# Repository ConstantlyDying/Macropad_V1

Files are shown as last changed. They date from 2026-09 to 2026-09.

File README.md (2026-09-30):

<p align="center">
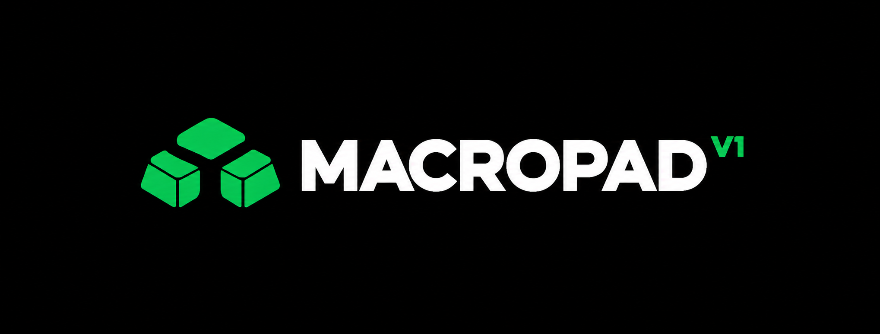
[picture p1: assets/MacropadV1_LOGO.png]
Macropad V1
  
</p>

<h1 align="center">MACROPAD V1</h1>

<p align="center">
  <strong>
    A wireless Raspberry Pi Pico W macropad with RGB lighting,
    rotary encoders, an OLED display and haptic feedback!
  </strong>
</p>

<div align="center">





</div>

<p align="center">
  <a href="#key-features">Key Features</a> •
  <a href="#pcb">PCB</a> •
  <a href="#case">Case</a> •
  <a href="#credits">Credits</a> •
  <a href="#license">License</a>
</p>

<p align="center">

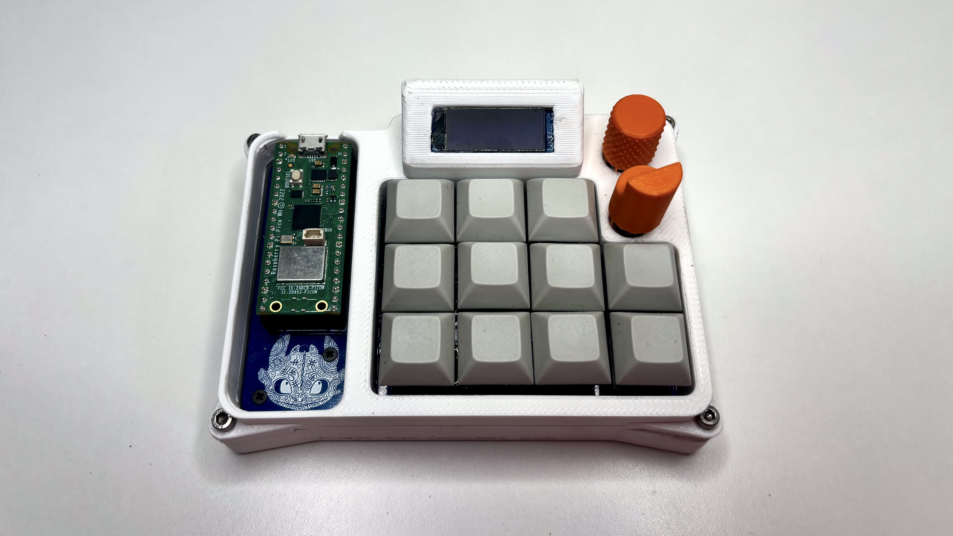
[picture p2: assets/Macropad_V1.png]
Macropad V1
  

</p>

I've made this as in my experience off the shelf macropads are way too expensive for the features they offer and are also very generic.
This is an alternative that is actually unique with multiple customizable switches, rotary encoders, a display, Wireless & Wired connectivity and insanely good haptics.

## Key Features

- **11 programmable keys** for custom shortcuts, macros, and commands
- **2 dedicated profile keys** for switching between profiles
- **Dual rotary encoders** for profile selection, volume, endless scrolling, and custom controls
- **OLED display** for showing the active profile and other information
- **Haptic feedback** for responsive physical feedback
- **QMK firmware** for controlling everything through the Pico
- **Vial configuration** for remapping keys and controls without reflashing firmware

## PCB 

Designed in KiCad!

### Schematic

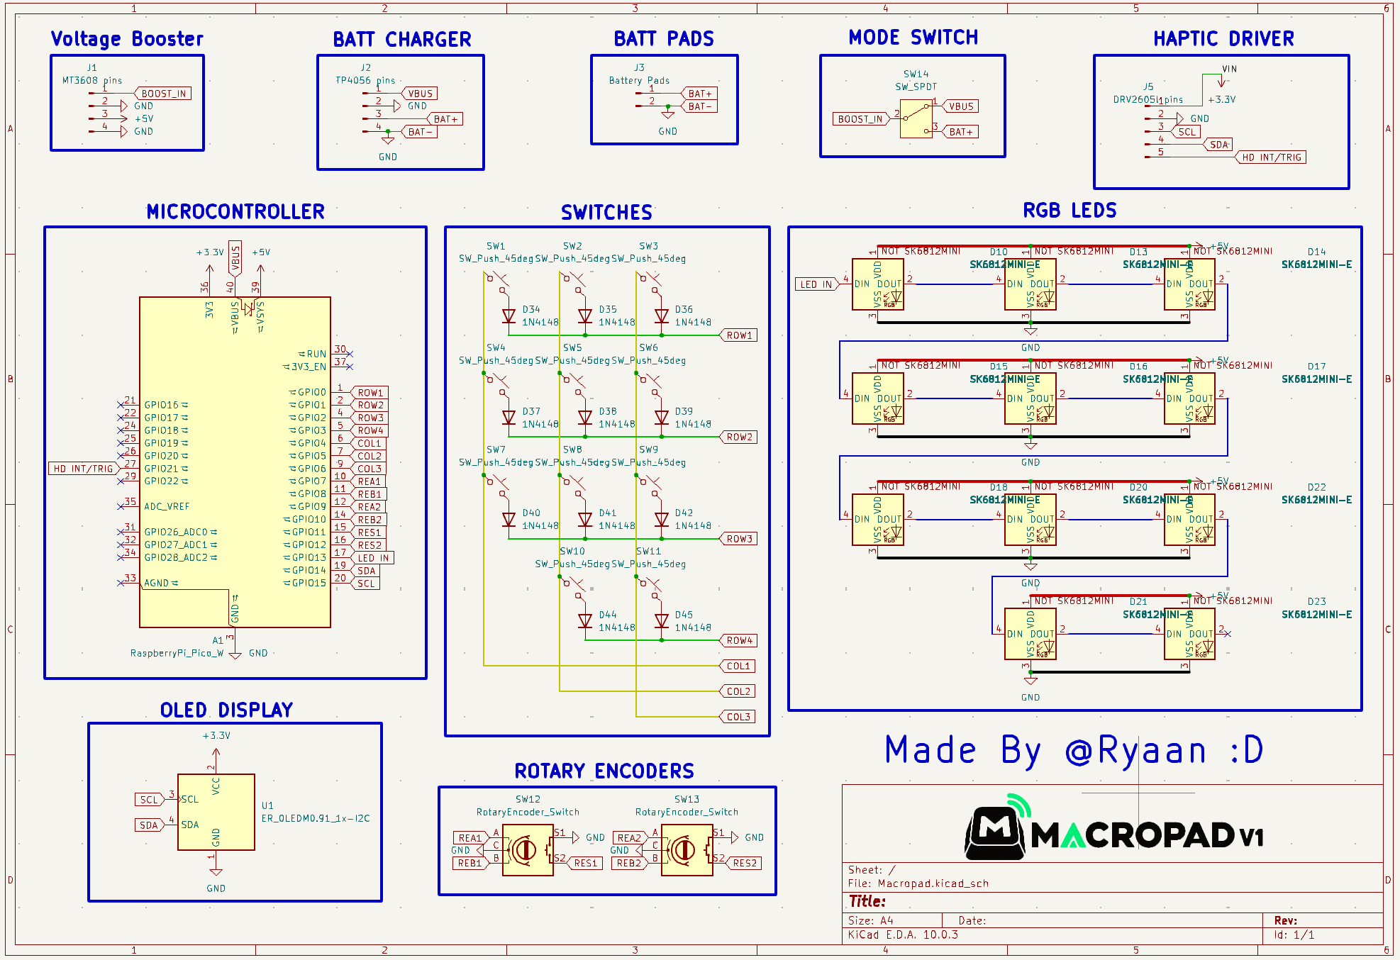
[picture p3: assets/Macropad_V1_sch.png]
Macropad V1 schematic
  

</p>

### PCB Layout:

**Front:**

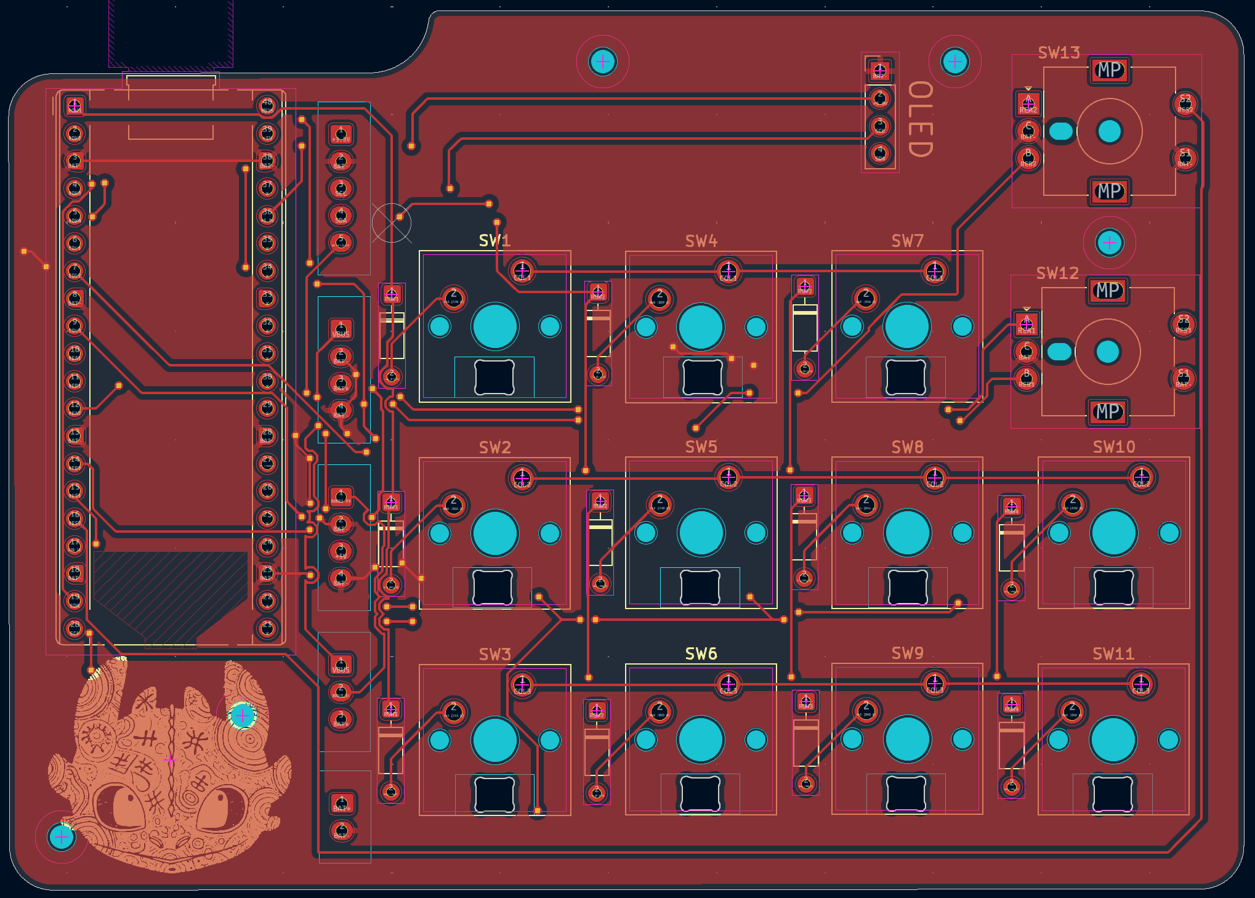
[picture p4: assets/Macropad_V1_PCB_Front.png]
Macropad V1 schematic
  

</p>

**Back:** 

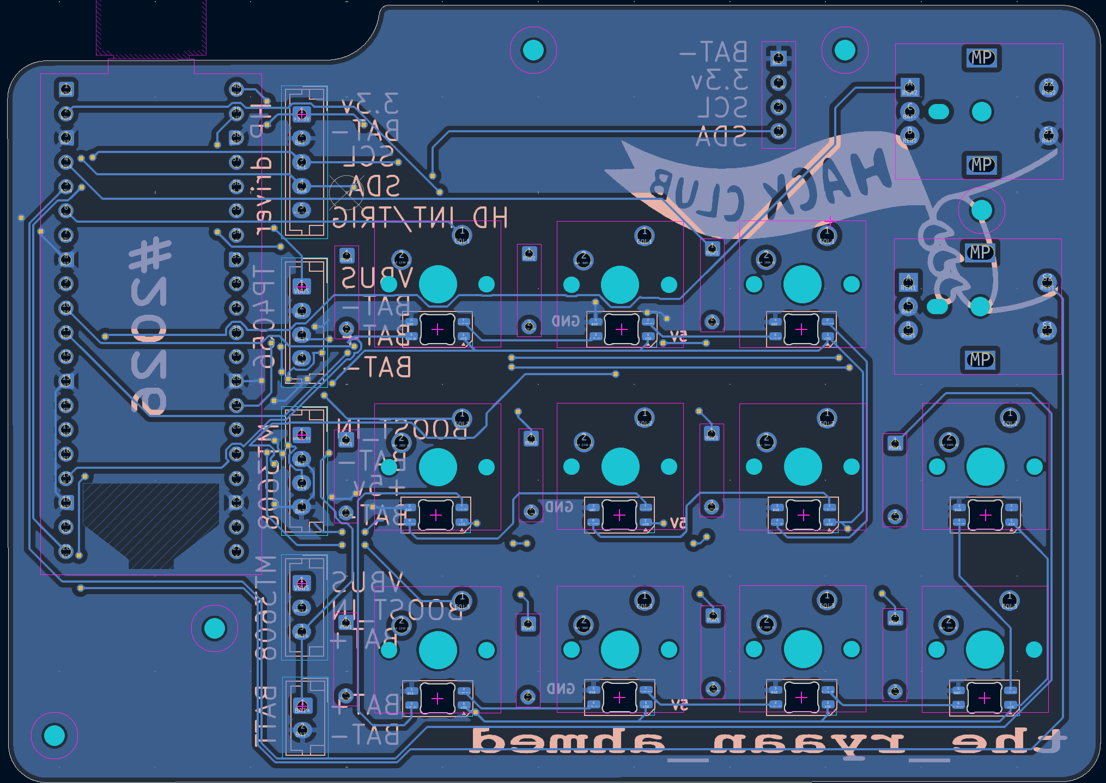
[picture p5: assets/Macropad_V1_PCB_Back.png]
Macropad V1 schematic
  

</p>

### Copper Layers:

**F_Cu:**

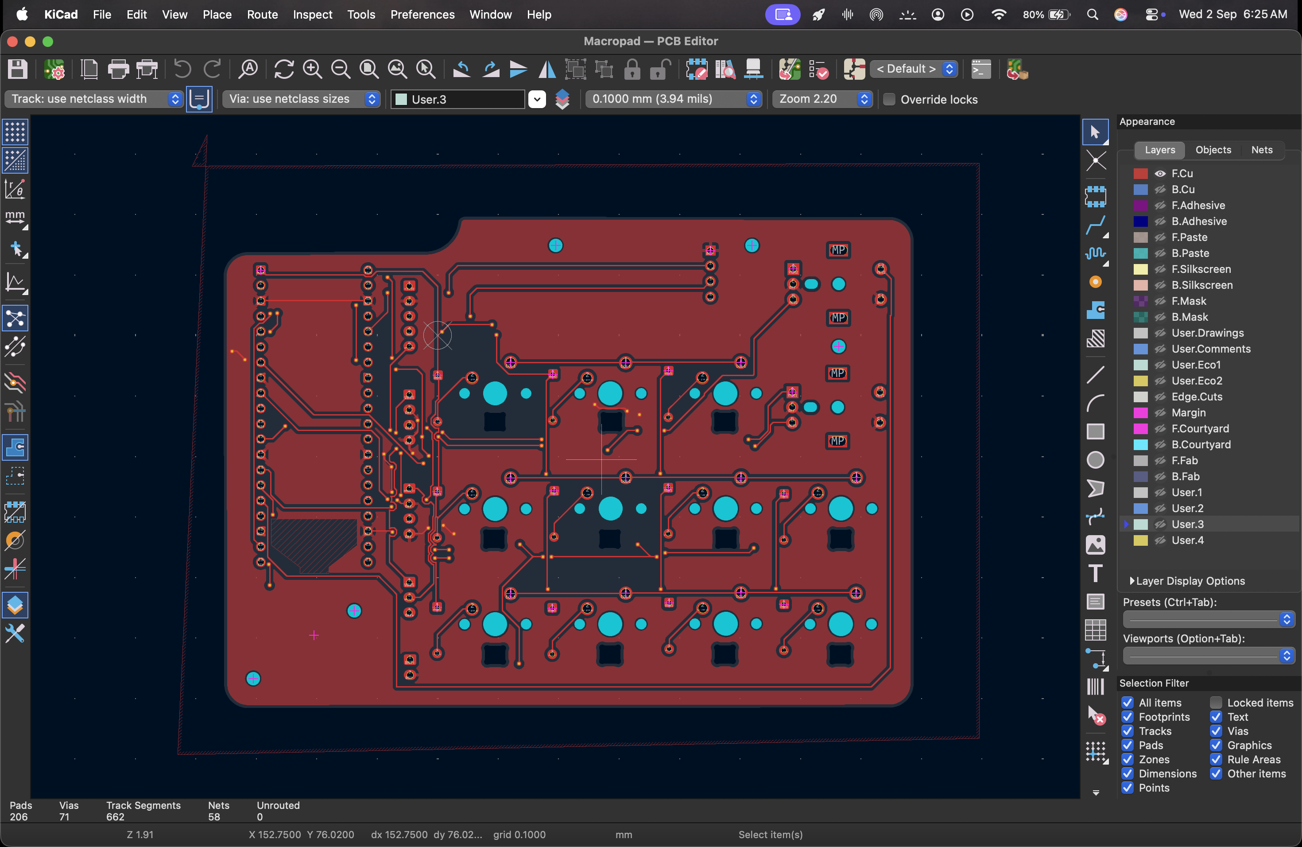
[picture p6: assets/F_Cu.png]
  

</p>

**B_Cu:**

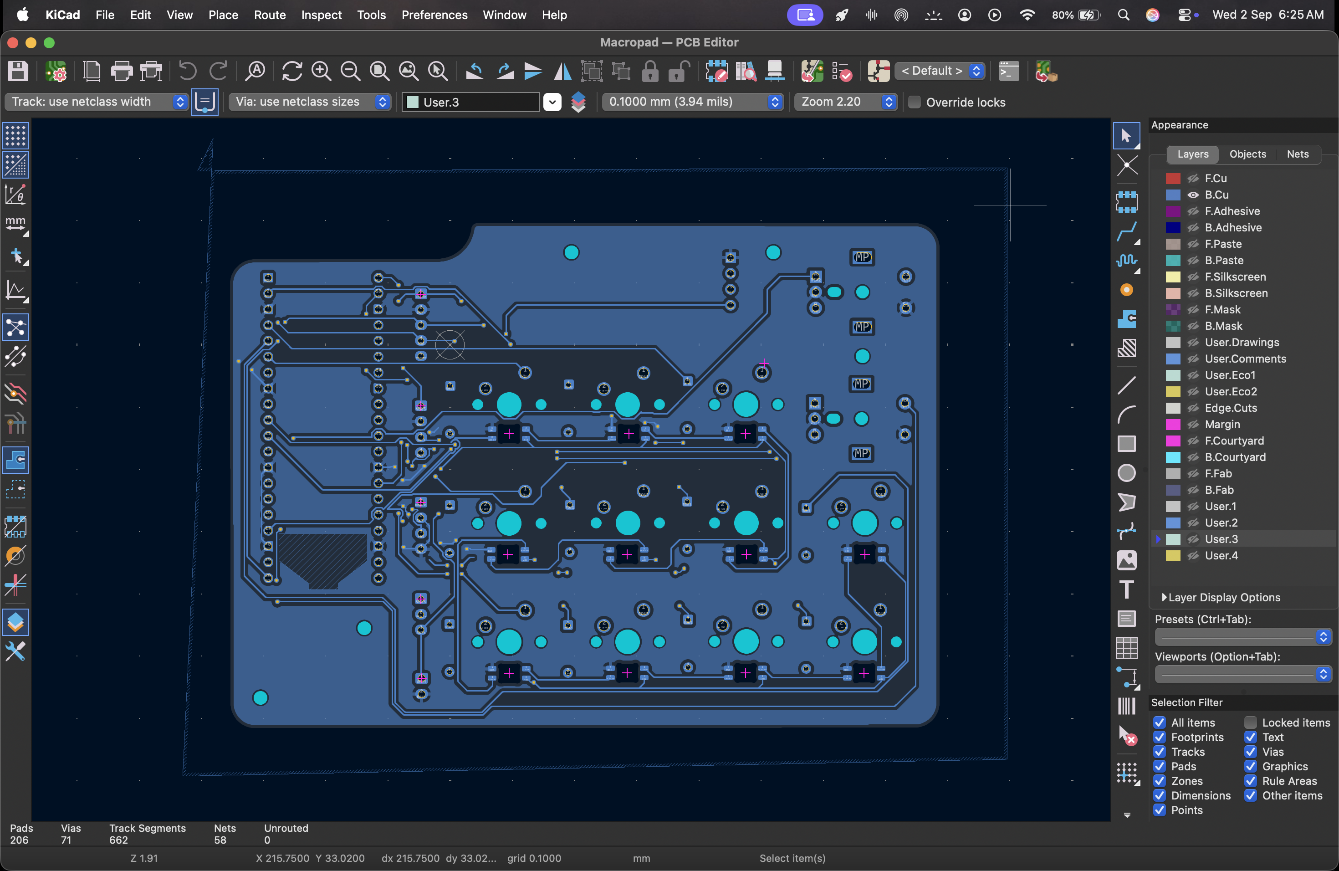
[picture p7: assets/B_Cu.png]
  

</p>

Board dimensions: 115mm x 80mm

## Case

Custom designed case in Fusion 360 with practical features:

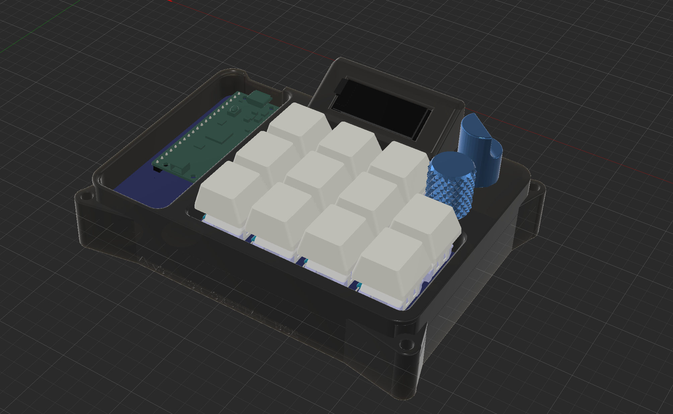
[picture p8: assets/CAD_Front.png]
Case Front View

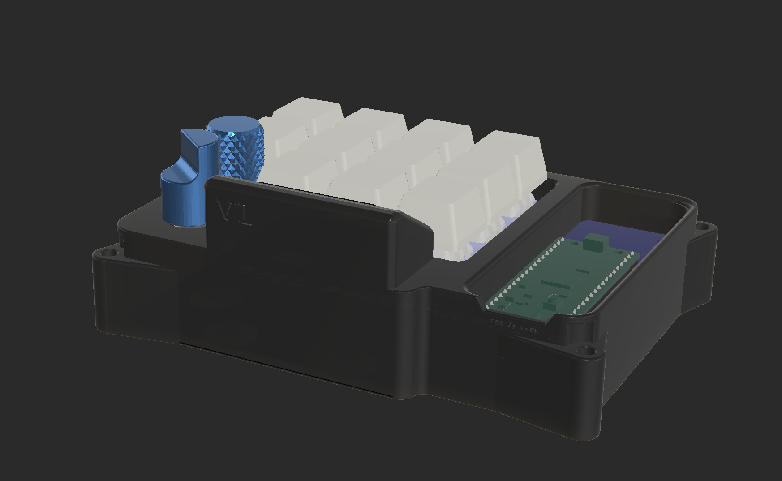
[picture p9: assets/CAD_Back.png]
Case Back View


Features:
- **USB port cutout** with flush cable routing
- **Raised-Angled Display** for easier status and profile viewing
- **Heatset inserts** for secure assembly with slotted cylindrical head screws
- **Rounded corners** for aesthetics and safety

## 3D Renders

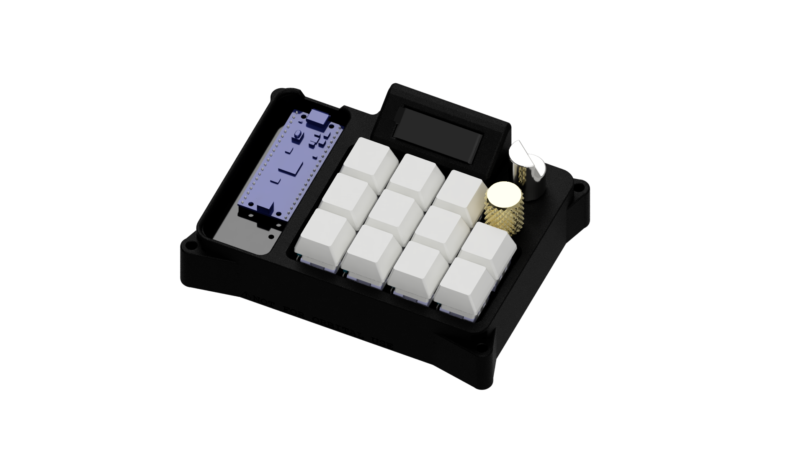
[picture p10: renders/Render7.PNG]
Render 1

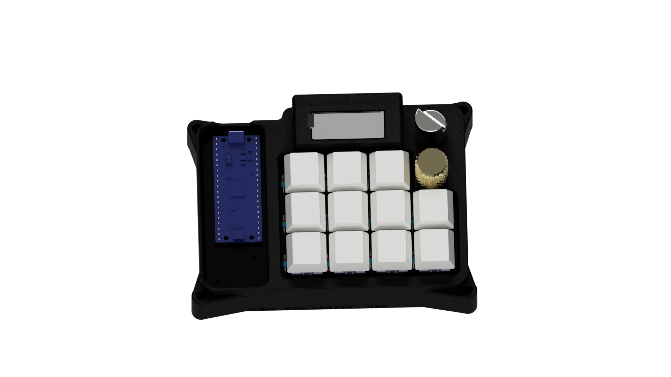
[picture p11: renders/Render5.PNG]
Render 1

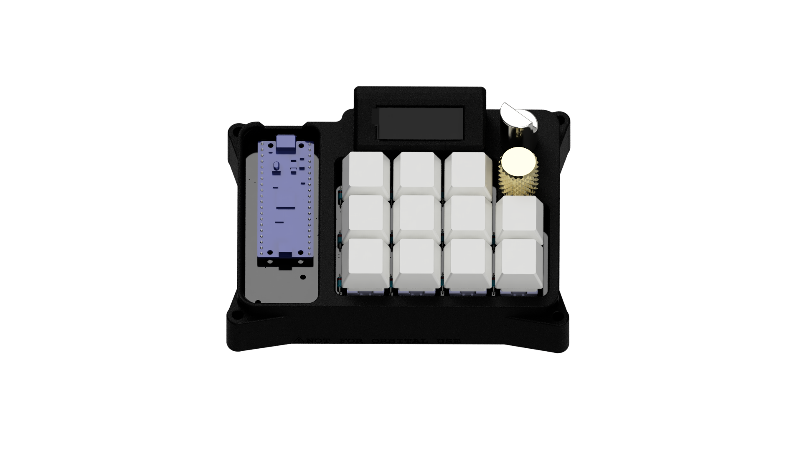
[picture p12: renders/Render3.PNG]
Render 1

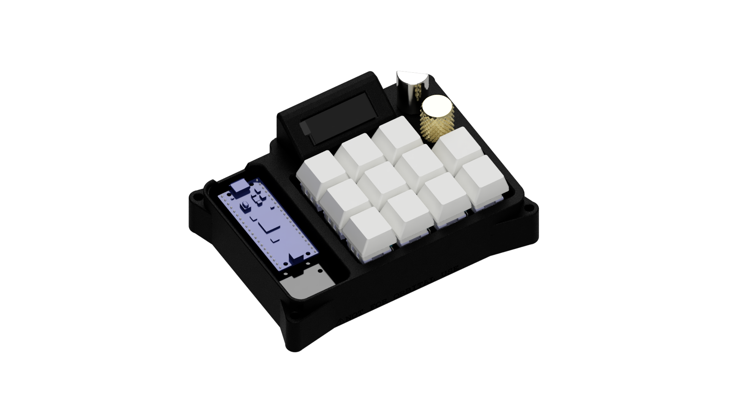
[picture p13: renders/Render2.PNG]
Render 1

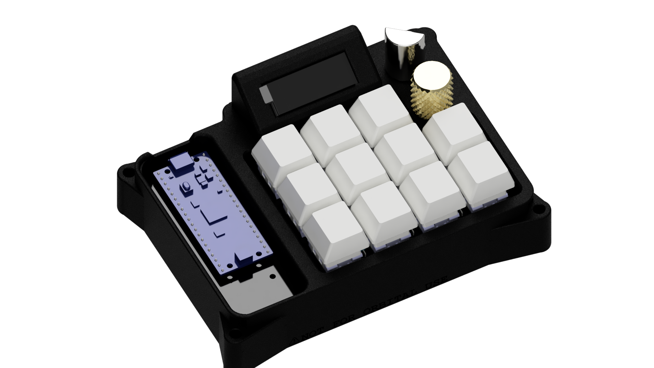
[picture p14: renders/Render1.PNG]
Render 1


## Credits

This project uses:

- [KiCad](https://www.kicad.org/)
- [Autodesk Fusion](https://www.autodesk.com/) for case design and renders
- [RaspberryPi](https://www.raspberrypi.com)
- [QMK](https://qmk.fm/) for the firmware

## You may also like...

- [Force-Feedback-Racing-Sim](https://github.com/ConstantlyDying/Force-Feedback-Racing-Sim) – A Budget friendly - DIY Racing simulator, powered by an Arduino Leonardo and a beefy 500w motor!!

### AI USAGE DECLARATION:
Used AI for a little assistance with firmware as it is my first time programming in these languages

## License

MIT

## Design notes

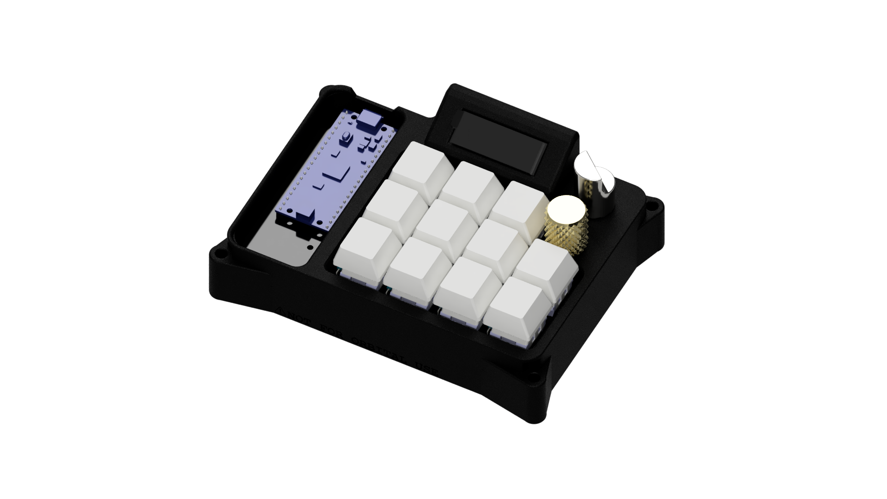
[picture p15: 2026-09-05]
renders/Render6.PNG

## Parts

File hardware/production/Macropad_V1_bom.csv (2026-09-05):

Designator | Footprint | Quantity | Value | LCSC Part #
A1 | RaspberryPi_Pico_Common_THT | 1 | RaspberryPi_Pico_W
D10, D13, D14, D15, D16, D17, D18, D20, D21, D22, D23 | LED_SK6812MINI-E_3.2x2.8mm_P1.5mm_ReverseMount | 11 | SK6812MINI-E
D34, D35, D36, D37, D38, D39, D40, D41, D42, D44, D45 | D_DO-35_SOD27_P7.62mm_Horizontal | 11 | 1N4148
J1 | JST_EH_B4B-EH-A_1x04_P2.50mm_Vertical | 1 | MT3608 pins
J2 | JST_EH_B4B-EH-A_1x04_P2.50mm_Vertical | 1 | TP4056 pins
J3 | JST_EH_B2B-EH-A_1x02_P2.50mm_Vertical | 1 | Battery Pads
J5 | JST_EH_B5B-EH-A_1x05_P2.50mm_Vertical | 1 | DRV2605l pins
SW1, SW10, SW11, SW2, SW3, SW4, SW5, SW6, SW7, SW8, SW9 | SW_Cherry_MX_1.00u_PCB | 11 | SW_Push_45deg
SW12, SW13 | RotaryEncoder_Alps_EC11E-Switch_Vertical_H20mm_MountingHoles | 2 | RotaryEncoder_Switch
SW14 | JST_EH_B3B-EH-A_1x03_P2.50mm_Vertical | 1 | SW_SPDT
U1 | PinHeader_1x04_P2.54mm_Vertical | 1 | ER_OLEDM0.91_1x-I2C

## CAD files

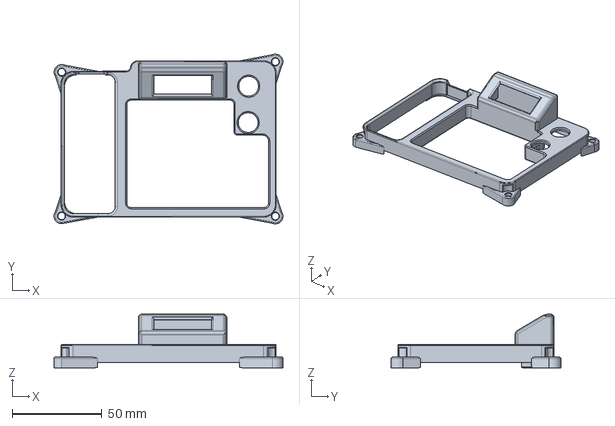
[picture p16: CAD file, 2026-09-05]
hardware/case/case top main.step
127.8 x 94.7 x 30.0 mm

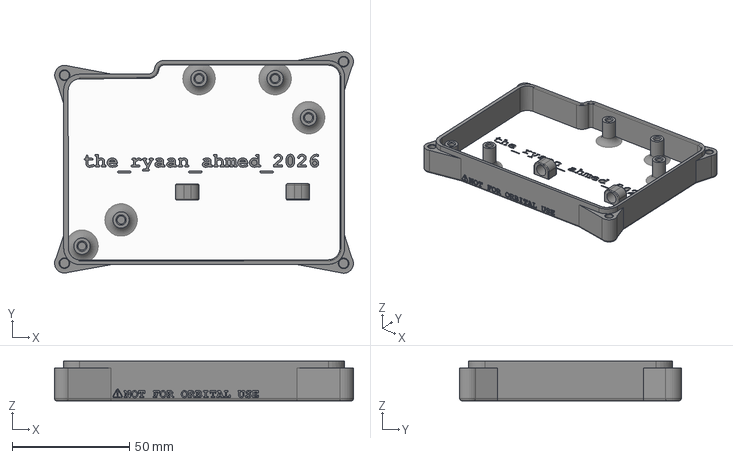
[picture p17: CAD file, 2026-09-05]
hardware/case/case bottom main.step
127.7 x 94.7 x 17.0 mm

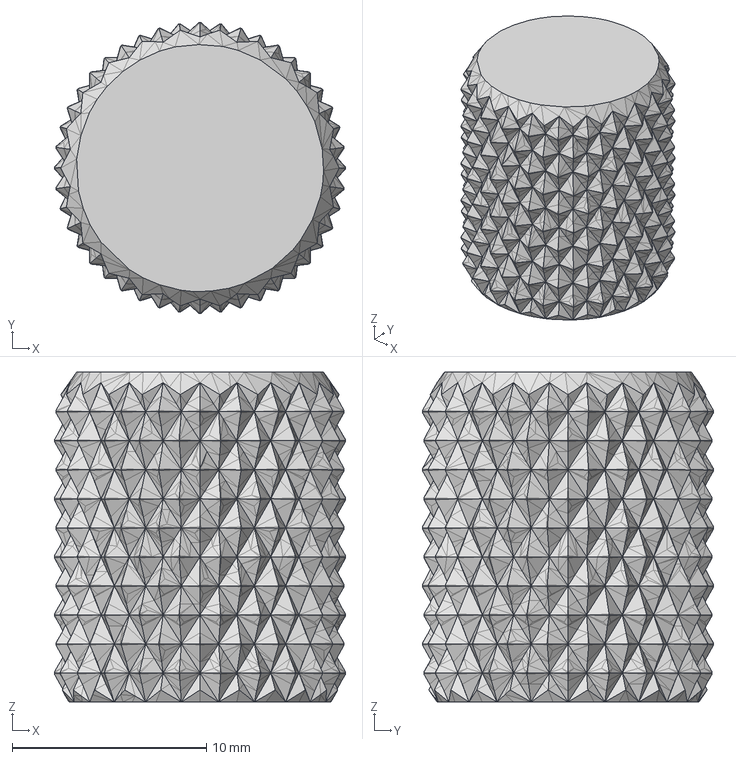
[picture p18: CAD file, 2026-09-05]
hardware/case/KNOB 2.step
15.0 x 15.0 x 17.0 mm

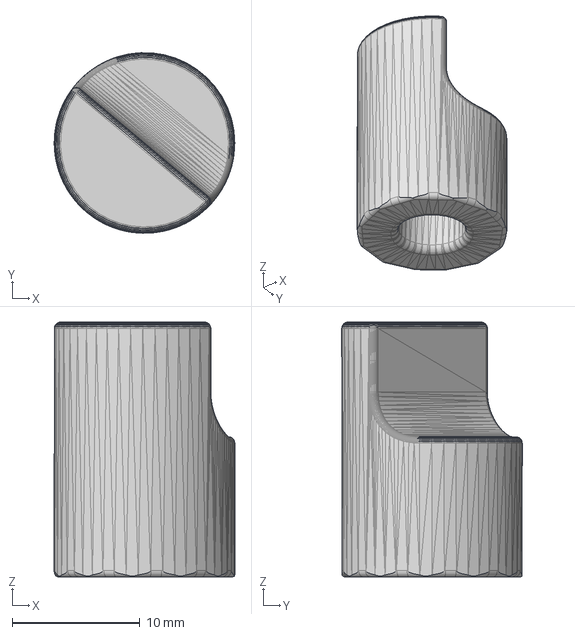
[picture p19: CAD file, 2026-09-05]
hardware/case/KNOB 1.step
14.2 x 14.2 x 20.0 mm

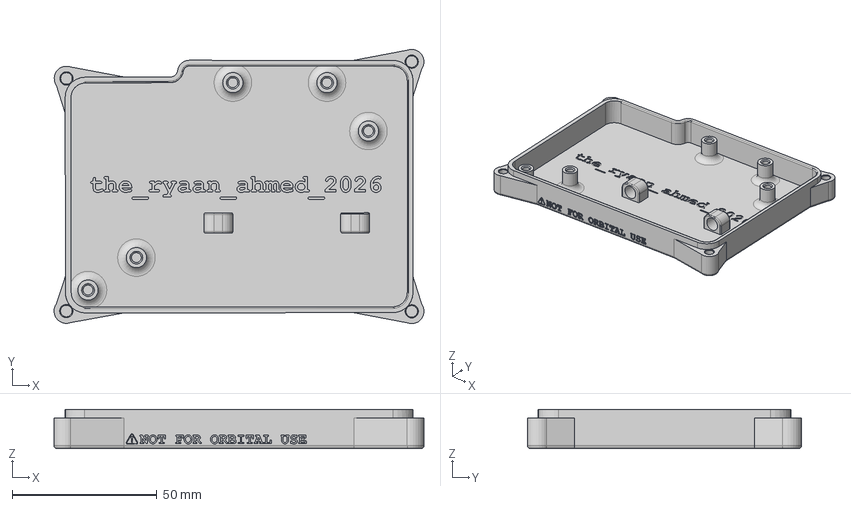
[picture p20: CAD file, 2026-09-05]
hardware/case/Macropad V1_CASE BOTTOM SLIM.step
127.7 x 94.7 x 13.5 mm

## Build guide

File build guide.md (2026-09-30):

# Build Guide:

### Step 1:
Get all the parts (Case top; case bottom; Soldered PCB; screws; Display: heated inserts).

### Step 2:
Insert the heated inserts into their places.

### Step 3:
Place the daughter boards and insert haptic actuator into its slot.
Place PCB on top of case bottom and screw it in place.

### Step 3:
Place case top on top of the PCB and case bottom and screw it in place.

### Step 4:
Connect the display with its connector and place it in its slot on case top.

### Step 5:
Plug the Pico in and flash the firmware.

### Step 6:
Attach all the keycaps and encoder caps.

### Step 7:
Done!!

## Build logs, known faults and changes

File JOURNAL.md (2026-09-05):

title: "Macropad"
author: "Ryaan"
description: "A wireless macropad with insane haptics!!, comes with 11 switches and 2 rotary encoders."
created_at: "2024-05-07"

# May 8th: Began working on my macropad idea

Today, i decided to start working on a macropad, as i submitted my other project and am impatient:)
I have no clue on how to build one, just heard its very popular. I mainly went around looking for inspiration, and how to start with the fundamentals like the schematics.
I imported a few libraries of symbols and foot prints to kicad. Now i have to figure out how to make a switch matrix, as im planning on using 11 switches along with 2 rotart encoders and a display, and the SEEED xiao MC barely has pins!! so yea.

https://public.lapse-hackclub.link/timelapses/Jx6Lpbg7D-ae/timelapse-Jx6Lpbg7D-ae.mp4







**Total time spent: 1h**

# May 9th: Continued working on schematics

I continued making the schematics. I went thru a few hackpads others made for inspirations, and to see if i can understand better by goin thru those schematics. I made the switch matrix, and added the rotary encoder sign. I also did a bit of research and am gonna go with the 0.91inch oled display. I also added diodes to the switches. Well im not sure how this goes, its my first time making a macropad:)

https://public.lapse-hackclub.link/timelapses/vdwkVHPgRyA7/timelapse-vdwkVHPgRyA7.mp4



**Total time spent: 1h 18m**

# May 10th: Continued working on schematics

i continued working on the schematics. I added and wired the switch matrix, rotary encoders, the oled display and the rgb led's. I just realised i wanna make the macropad wireless too, so im gonna add a raspbery pico W later.

https://public.lapse-hackclub.link/timelapses/AWpfal8JZQ22/timelapse-AWpfal8JZQ22.mp4





**Total time spent: 1h 32m**

# May 10th: Continued working on schematics

i continued working on my schematics:)
I finished re arranging all the components, and then wired them up, (colour coded obv). Then a random idea js struck my mind: why not make it wireless!
so i went ahead with a raspberry pi pico W, and started researching on how to make it wireless and functional.
I decided on like a 1000mah 3.7v battery(might change later tho..), and a TP4056 module for charging:)

https://public.lapse-hackclub.link/timelapses/nB5B7usA8Ic8/timelapse-nB5B7usA8Ic8.mp4





**Total time spent: 1h 3m**

# May 10th: Continued working on schematics

I am still continuing on my schematics lmaoo:)
As i thought of using whatever module im adding to my pcb as daughter modules, i had to find their symbols, which ofc were not there, so i just decided to use connectors instead. I then changed the name and labelled the pins on these connectors to math the TP4056. Then i added 2 connectors similarly for the battery pads and labelled them. I repeated the same for the MT3608 buck boost converter too. Then i added a spdt slide switch and wired them all up!. The main idea was that; there woul be two modes which the switch can toggle: one was the wired one, where the macropad gets connected via usb and doesn't use battery power, and the 2nd is wireless, where the macropad connects via bluetooth, utilizing the power of the battery.

https://public.lapse-hackclub.link/timelapses/LJAMLVG_SWli/timelapse-LJAMLVG_SWli.mp4



**Total time spent: 1h 1m**

# May 10th: Continued working on schematics

i forgot to save my kicad sch, and left the pc on. there was a power cut and almost all my work was gone:((, literally the 3rd time this is happening!!
So yea, i had to redo everything again:(((
This time i made the wiring neater ofc:)

https://public.lapse-hackclub.link/timelapses/aa1d4ZVKxRlv/timelapse-aa1d4ZVKxRlv.mp4






**Total time spent: 1h 3m**

# May 10th: Continiued working on schematics (assigned footprints etc)

I did some final touches and started working on assigning the foot prints to each.
i had a bit of trouble figuring out how to make like pads where i can solder the battery to, so i used mounting holes instead. I also got the idea of adding haptics:), i don't think any1 has done that b4 so should be fun:)). Im planning on using a drv2605l module for precisely controlling the haptics, and customising it for each mode. Like a different intensity and style while gaming, or while working, or while changing profiles.

https://public.lapse-hackclub.link/timelapses/4v5Tm7YbSgqZ/timelapse-4v5Tm7YbSgqZ.mp4



**Total time spent: 1h 12m**

# May 11th: Made some changes to original idea

I researched and added a new module for the haptics!!
I think this is the first hackpad with haptics too:)
Im gonna go with the Adafruit DRV2605L Haptic Motor Controller, this is insane for controlling vibrations precisely. It can do multiple types too, like a quick i phone like one, or bit more detailed like the psg controllers, this is ofc customizable and can be changed depending on your profiles:). I then opened the pcb editor for the first time and tried to dump the footprints, but there was some error: it turns out i cant use mounting holes to solder wires onto, so i just swapped it out for some pin headers, which should do the job just fine. now the error got fixed and i dumped the components, Im new to this stuff, so i just arranged the switches, and am gonna do the rest later. I wanna hide the pico or somehow mount it smd style so its huge footprint doesnt make the the entire macropad bigger. I think i might rather use a different MC if the pico won't be able to mount on the underside of the pcb.

https://public.lapse-hackclub.link/timelapses/szlrLOvkwOXQ/timelapse-szlrLOvkwOXQ.mp4









**Total time spent: 1h 41m**

# May 14th: Continued working on schematics

I made the schematics much neater. Aryan introduced me to global labels on Kicad which is a lifesaver. I also used a better looking symbol for the switches. I then made a new switch matrix, and wired everything up using global labels. I also rearrranged every symbol and labelled everything neatly so that my schematics could look more professional:). I also redumped all my footprints onto the pcb editor as ive edited each of the them in the footprint assigner thingy. Im still not sure about the pcb part tho, and am on the fence about choosing a raspberry pi pico w or not, due to its HUGE footprint.

https://public.lapse-hackclub.link/timelapses/0GBBIOc-dRC7/timelapse-0GBBIOc-dRC7.mp4







**Total time spent: 1h 30m**

# May 21nd: Started working on the pcb

I started working on the pcb finally. Well this is my forst time making a pcb, so yea
I just imported all the footprints onto the editor. I then arranged them roughly, i have no clue if its correct or not. I will def change them later. I arranged only the switches, rotary encoder and pico for now.

https://lapse.hackclub.com/timelapse/G3J0O8FZEjo2





**Total time spent: 30m**

# May 22nd: Transferred all the journals to horizons

I just transferred all the journals from fallout to horizons neatly. I ensured each journal correctly alligned with the guidelines for horizons.

https://lapse.hackclub.com/timelapse/SRcNPL15U1K1



**Total time spent: 40m**

# May 23rd: Continued working on pcb

i continued working on the schematics. I thought of placing the pico underneath the pcb but realised that wont work cuz if the switches. I then tried doing some research on some other module with a smaller footprint like a xiao or a rp2040 or an esp32 etc, but everything was either too big or too small, didnt have enough gpios or had too many etc etc. I went through lots of datasheets etc and still no luck. I decided to give the esp32 s3 a try, not sure tho...

https://lapse.hackclub.com/timelapse/vrI20fQrQSxk






**Total time spent: 2h 15m**

# June 4th: Worked on the schematica

I did most of my work on the schematics today. I decided to ditch the esp32 mc or any other mcu idea as i didnt wanna over complicate anything for my first pcb, and my first macropad. Im gonna stick with the pico only. I made some changes to the connections of the power switch and all the daughter modules.

https://lapse.hackclub.com/timelapse/ZglHSRn_m3mC




**Total time spent: 40m**

# June 14th: Continued working on the pcb

I continued working on the pcb. I arranged the diodes near each key, and placed the leds under each key. I also flipped the leds. I tried different positions for the pico so it can be compact, but gave up:), i then made the pico foortprint from smd to pin header one. I also moved around the pin headers for the daughter modules, and then decided to ditch the pin headers and instead connect the modules with jst connectors as then i can place the modules on the bottom of the case and it will be easier to wire too.

https://lapse.hackclub.com/timelapse/cCD02lNH7a1F





**Total time spent: 3h 30m**

# June 14th: Continued working on pcb

I continued working on the pcb. I went thru the schematics once more. I then downloaded some cherry mx key switches 3d models and added them to the foot print properties. I also added the keycaps too. I did added the ec11 encoder cad but culdnt finda suitable knob yet. I then started setting the editor with defferent track widths etc, and netclass, to start routing the pcb, as this is my first time. I somehow routed all the switches and the encoder and the oled disp. Im yet to do the rest. As of now the routing is insanely messy, with like a ton of vias everywhere.

https://lapse.hackclub.com/timelapse/yGzgsLiheN3N






**Total time spent: 3h 30m**

# June 17th: Continued working on pcb

I continued working on the pcb. I deleted all tracks and vias cuz they were too ugly.
I started routing it again from scratch after a few yt videos. Soon into routing i realised that i had to rearrange switches and the leds accoording to their matrix ro the routing will get messed up. That was confusing and took a while. I then connected the diodes, then the switches according to the matrix, then the leds. I also connected all these to the MC, including the pins and everything for the daughter modules and the rotary encoders. I only have to route the gnd later.

https://lapse.hackclub.com/timelapse/9O0yEaNH6vYd





**Total time spent: 3h 5m**

# June 24th: Continued working on the pcb

I continued working on my pub, but on a Mac this time. Im new to ts so I’m still figuring stuff out.
I wired all the components (routing) except the gnd ones. I then had to figure out how to do the ground plane or whatever and how to connect stuff to it. I made some rectangle and clicked b and it did the job. Then I had to connect the parts of the pcb where the ground plane were not proper, that took a while, and too all the tracks were routed. I then went ahead on adding the cad versions of the cherry mx key switches, keycaps, encoder, and the old display. Yes I had done this before but I had to redo cuz when I imported the stuff to Mac, the cad didn’t as they were not in the Mac locally, so yea I assigned the 3d model to each. I will have to do the silkscreen next, add mounting holes and maybe edit the board shape too a bit.

 https://lapse.hackclub.com/timelapse/HNFu5uJsJ8_N





**Total time spent: 2h 30m**

# June 29th: Continued working on the pcb

Added the mounting holes. Improved the edge cuts, took be a while to figure out how to properly make curved edge cuts on the pcb. I then re added the net fill thingy. I then looked for a few graphics to put as my silkscreen, I decided to go with toothless and hack club logo flag. I also added names for headers of all the daughter modules including the oled display. Kicad started lagging when i added certain images like the fallout logo. I had to find a proper image so it doesnt look like a blot on the silk screen.

https://lapse.hackclub.com/timelapse/fDKLNE7e71vV








**Total time spent: 3h 30m**

# June 30th:  Continued working on the pcb

I finalised the silkscreen, and cleaned it up on both the front and the back. I then checked for any broken connections, found one wire unrooted for some reason and fixed it.  I then started making the repo. I added files called PCB and Schematics, which contained the respective files with their screenshots. I dont know why but I had to convert all the screenshots I took into pdfs before uploading as GitHub kept showing some error. I also tried adding more graphics to the silkscreen, but for some reason that did not work, and also ended up causing my laptop to lag. I also made the readme with some general screenshots, talked about what it is, why I made it, and a little about the pcb and schematics.

Screenshot 2026-06-30 at 12 11 14 AM
Screenshot 2026-06-30 at 12 10 52 AM
Screenshot 2026-06-30 at 12 09 26 AM
Screenshot 2026-06-30 at 12 09 26 AM

**Total time spent: 2h**

# July 12th: Fixed the Repo and some other stuff

I Started to work on the CAD part of my macropad, which was basically an enclosure for the macropad in fusion, i have no clue what to do in fusions so will resume that a bit later. I then got notified that my project got rejected due to no BOM, so I fixed my repo and added a BOM

https://lapse.hackclub.com/timelapse/cSW4kQ45cI7v



**Total time spent: 55m**

# July 23th: Started assembling everything on the PCB

I started to solder everything onto my pcb- the leds, switches, headers, oled disp, MC, rotary encoders, JST connectors and diodes.
The sk6812 were a pain to solder by hand, this is my first time hand soldering smd electronics so i underestimated how hard they would be with basic tools, the soldering iron, solder and the flux i had were of pretty poor quality so the solder almost never flowed properly. The leds probably took the longest (i even melted one 💀). the diodes, headers and jst connectors were comparatively easy to solder with the helping hand. The switches were too; just that i had to resolder almost everyone of them cuz they seemed tilted (i mightve gotten scammed, the cherry mx switches i gought didnt have those alignment things on their base) and make all of them properly aligned. I have to solder the mt 3608 and the tp4056 next

https://lapse.hackclub.com/timelapse/PsYyGIHk7pCl



**Total time spent: 5h 25m**

# July 25th: Debugged the PCB with components

I tested the functionality of the pcb with everything soldered onto the pcb - the switches, LEDs, MC,headers, oled disp, rotary encoders, JST connectors and diodes. Everything worked, the leds were flashing and the keys were inputting numbers onto my pc, the display showed the bongo cat.

https://lapse.hackclub.com/timelapse/tcPYSnsSdNUo



**Total time spent: 2h **

# August 1th: Began CAD of the case

I started working on the case on fusion, this is my first time on the software so i am still figuring stuff out. I imported the step file of the pcb from kicad, and used it as the reference to make the base of the pcb. I added bosses under each mounting hole and drilled it to fit heated inserts, this took a while as i couldnt figure out how to choose the base to extrude from, i kept selecting the pcb and the bosses came out of the pcb, i had to then make a new plane lol and finally did it. I also made the walls about 1mm away from the pcb to give some tolerance.

https://lapse.hackclub.com/timelapse/vCLISJI7L-JC



**Total time spent: 2h **

# August 5th: Upper part of the case

I made the upper part of the case, it got really confusing as to what i should project, extrude, shell etc, so i had to redo some stuff again cuz for some reason shell function is different here than onshape. Getting the cutouts right, and having the walls at the correct height took so long. I even made the oled display raised and facing me, this took a while as for some reason the edges were curved!!, i couldnt constraint properly etc etc, then i finally have something presentable now.

https://lapse.hackclub.com/timelapse/t9u9HI_tvhNb



**Total time spent: 5h 15m **

# August 9th: Polishing and final touches

Polished everything, did checks on all the components. added chamfers fillets etc. Also added name and some text engravings. When i fixed something in a specific component early on in the timeline, the rest of the stuff like the sketches, chamfers and things which depended on this, this was a pain to fix, as its my first time on fusion, and had to redo some stuff here and there.
Added the knobs too

https://lapse.hackclub.com/timelapse/wzWPh33OKpZP





**Total time spent: 3h **

# August 14th: Keyswitch Cutout On Upper part of case

Added the cutouts for keyswithces on the top part of the case cuz i just remembered, also filleted and polished it.
Its done i think, maybe will do renders later.

https://lapse.hackclub.com/timelapse/rpi19juy3fH7



**Total time spent: 1h **

# August 29th: Assembly of Macropad

The 3d prints finally arrived. I had to use weird methods to remove the supports from the top case, the curved prints looked a bit uneven, so ill have to fix that in my design next time. I made two versions for the bottom part, one is thincker and the other is slimmer. I then inserted the heated inserts with my soldering iron to both the bottom cases. I had do resolder the oled display with a jst connector instead of the header as i had to stick the display on the case, this took an awful lot of time as i didnt have a desoldering pump or wick. I then made the wires connecting the vibration motor to its driver and the driver connecting the driver to the pcb shorter, to save space inside the case. I then inserted the motors into their holes and screwed on the pcb and both the cases together.

https://lapse.hackclub.com/timelapse/wpPop1HO6Bq8

0C5C566D-EEBF-43D0-92ED-6E436D2148A6_1_102_o
1144C3E7-0BA0-4276-B244-6303433435E0_1_102_o

**Total time spent: 2h 20m **

# September 4-6th: Finishing and Polishing Repo

Cleaned up my old repo, made it much more polished now. rearranged the folders and files neatly. Made renders of the macropad in fusion as idk about blender yet, not very satisfied with the render, might make new ones later!. I love how the readme turned out compared to my older repo's, definitely learnt something there!

https://lapse.hackclub.com/timelapse/PuxxIOakvZ14
https://lapse.hackclub.com/timelapse/toAW4w7KC8Dp





**Total time spent: 4h **

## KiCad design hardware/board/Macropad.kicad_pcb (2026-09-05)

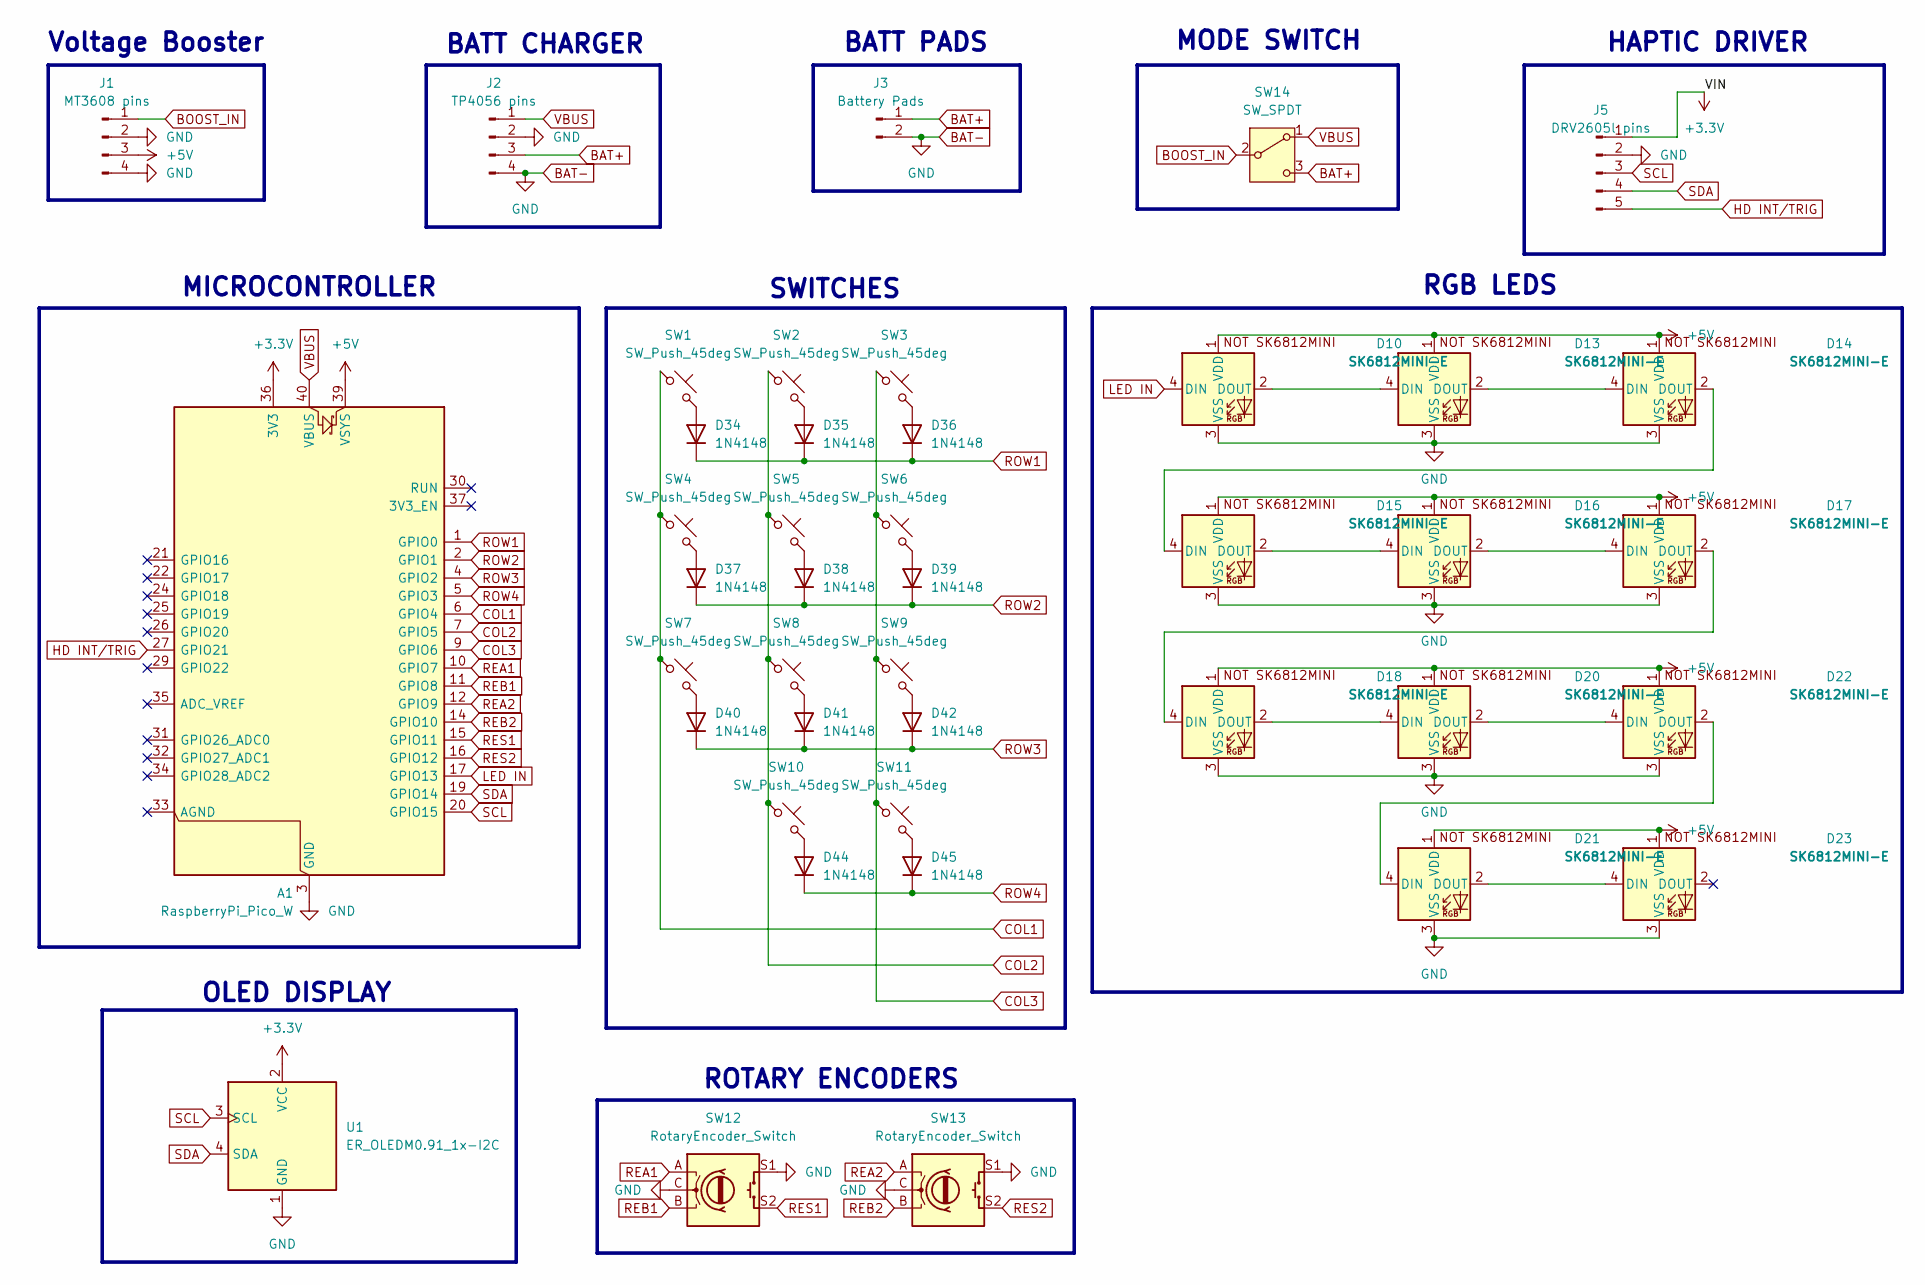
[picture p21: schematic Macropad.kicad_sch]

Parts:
A1: RaspberryPi_Pico_W; RaspberryPi_Pico_Common_THT
D10, D13, D14, D15, D16, D17, D18, D20, D21, D22, D23: SK6812MINI-E; LED_SK6812MINI-E_3.2x2.8mm_P1.5mm_ReverseMount
D34, D35, D36, D37, D38, D39, D40, D41, D42, D44, D45: 1N4148; D_DO-35_SOD27_P7.62mm_Horizontal
J1: MT3608 pins; JST_EH_B4B-EH-A_1x04_P2.50mm_Vertical
J2: TP4056 pins; JST_EH_B4B-EH-A_1x04_P2.50mm_Vertical
J3: Battery Pads; JST_EH_B2B-EH-A_1x02_P2.50mm_Vertical
J5: DRV2605l pins; JST_EH_B5B-EH-A_1x05_P2.50mm_Vertical
SW1, SW2, SW3, SW4, SW5, SW6, SW7, SW8, SW9, SW10, SW11: SW_Push_45deg; SW_Cherry_MX_1.00u_PCB
SW12, SW13: RotaryEncoder_Switch; RotaryEncoder_Alps_EC11E-Switch_Vertical_H20mm_MountingHoles
SW14: SW_SPDT; JST_EH_B3B-EH-A_1x03_P2.50mm_Vertical
U1: ER_OLEDM0.91_1x-I2C; PinHeader_1x04_P2.54mm_Vertical

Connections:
+3.3V: A1.36 (3V3), J5.1, U1.2 (VCC)
+5V: A1.39 (VSYS), D10.1 (VDD), D13.1 (VDD), D14.1 (VDD), D15.1 (VDD), D16.1 (VDD), D17.1 (VDD), D18.1 (VDD), D20.1 (VDD), D21.1 (VDD), D22.1 (VDD), D23.1 (VDD), J1.3
BAT+: J2.3, J3.1, SW14.3 (C)
BAT-: A1.3 (GND), A1.8 (GND), A1.13 (GND), A1.18 (GND), A1.23 (GND), A1.28 (GND), A1.38 (GND), D10.3 (VSS), D13.3 (VSS), D14.3 (VSS), D15.3 (VSS), D16.3 (VSS), D17.3 (VSS), D18.3 (VSS), D20.3 (VSS), D21.3 (VSS), D22.3 (VSS), D23.3 (VSS), J1.2, J1.4, J2.2, J2.4, J3.2, J5.2, SW12.C, SW12.S1, SW13.C, SW13.S1, U1.1 (GND)
BOOST_IN: J1.1, SW14.2 (B)
COL1: A1.6 (GPIO4), SW1.1, SW4.1, SW7.1
COL2: A1.7 (GPIO5), SW2.1, SW5.1, SW8.1, SW10.1
COL3: A1.9 (GPIO6), SW3.1, SW6.1, SW9.1, SW11.1
HD INT/TRIG: A1.27 (GPIO21), J5.5
LED IN: A1.17 (GPIO13), D10.4 (DIN)
unnamed: D10.2 (DOUT), D13.4 (DIN)
unnamed: D13.2 (DOUT), D14.4 (DIN)
unnamed: D14.2 (DOUT), D15.4 (DIN)
unnamed: D15.2 (DOUT), D16.4 (DIN)
unnamed: D16.2 (DOUT), D17.4 (DIN)
unnamed: D17.2 (DOUT), D18.4 (DIN)
unnamed: D18.2 (DOUT), D20.4 (DIN)
unnamed: D20.2 (DOUT), D22.4 (DIN)
unnamed: D21.4 (DIN), D22.2 (DOUT)
unnamed: D21.2 (DOUT), D23.4 (DIN)
unnamed: D34.2 (A), SW1.2
unnamed: D35.2 (A), SW2.2
unnamed: D36.2 (A), SW3.2
unnamed: D37.2 (A), SW4.2
unnamed: D38.2 (A), SW5.2
unnamed: D39.2 (A), SW6.2
unnamed: D40.2 (A), SW7.2
unnamed: D41.2 (A), SW8.2
unnamed: D42.2 (A), SW9.2
unnamed: D44.2 (A), SW10.2
unnamed: D45.2 (A), SW11.2
REA1: A1.10 (GPIO7), SW12.A
REA2: A1.12 (GPIO9), SW13.A
REB1: A1.11 (GPIO8), SW12.B
REB2: A1.14 (GPIO10), SW13.B
RES1: A1.15 (GPIO11), SW12.S2
RES2: A1.16 (GPIO12), SW13.S2
ROW1: A1.1 (GPIO0), D34.1 (K), D35.1 (K), D36.1 (K)
ROW2: A1.2 (GPIO1), D37.1 (K), D38.1 (K), D39.1 (K)
ROW3: A1.4 (GPIO2), D40.1 (K), D41.1 (K), D42.1 (K)
ROW4: A1.5 (GPIO3), D44.1 (K), D45.1 (K)
SCL: A1.20 (GPIO15), J5.3, U1.3 (SCL)
SDA: A1.19 (GPIO14), J5.4, U1.4 (SDA)
VBUS: A1.40 (VBUS), J2.1, SW14.1 (A)

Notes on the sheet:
OLED DISPLAY
Voltage Booster
MICROCONTROLLER
BATT PADS
RGB LEDS
HAPTIC DRIVER
SWITCHES
ROTARY ENCODERS
MODE SWITCH
BATT CHARGER

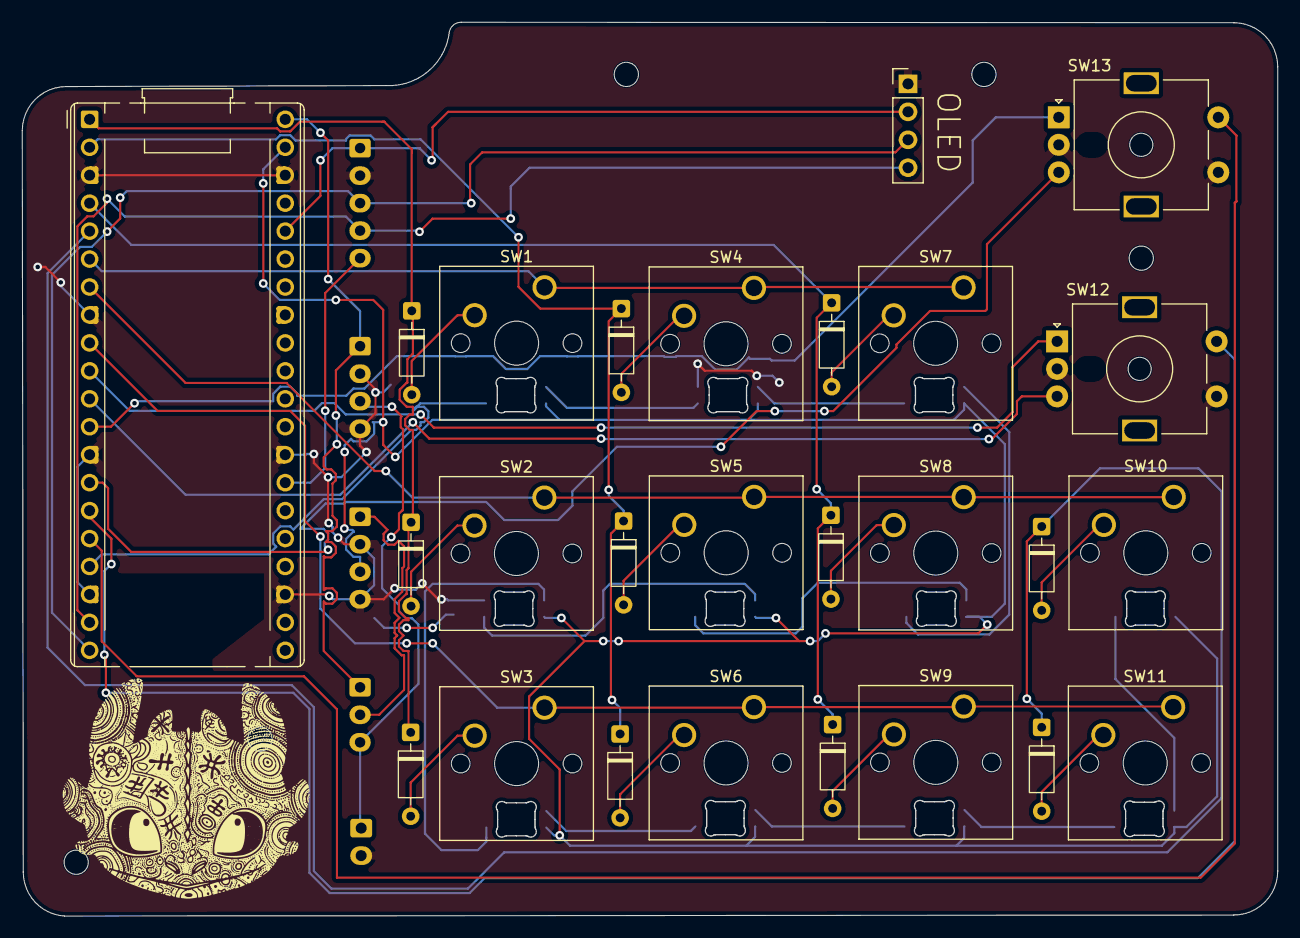
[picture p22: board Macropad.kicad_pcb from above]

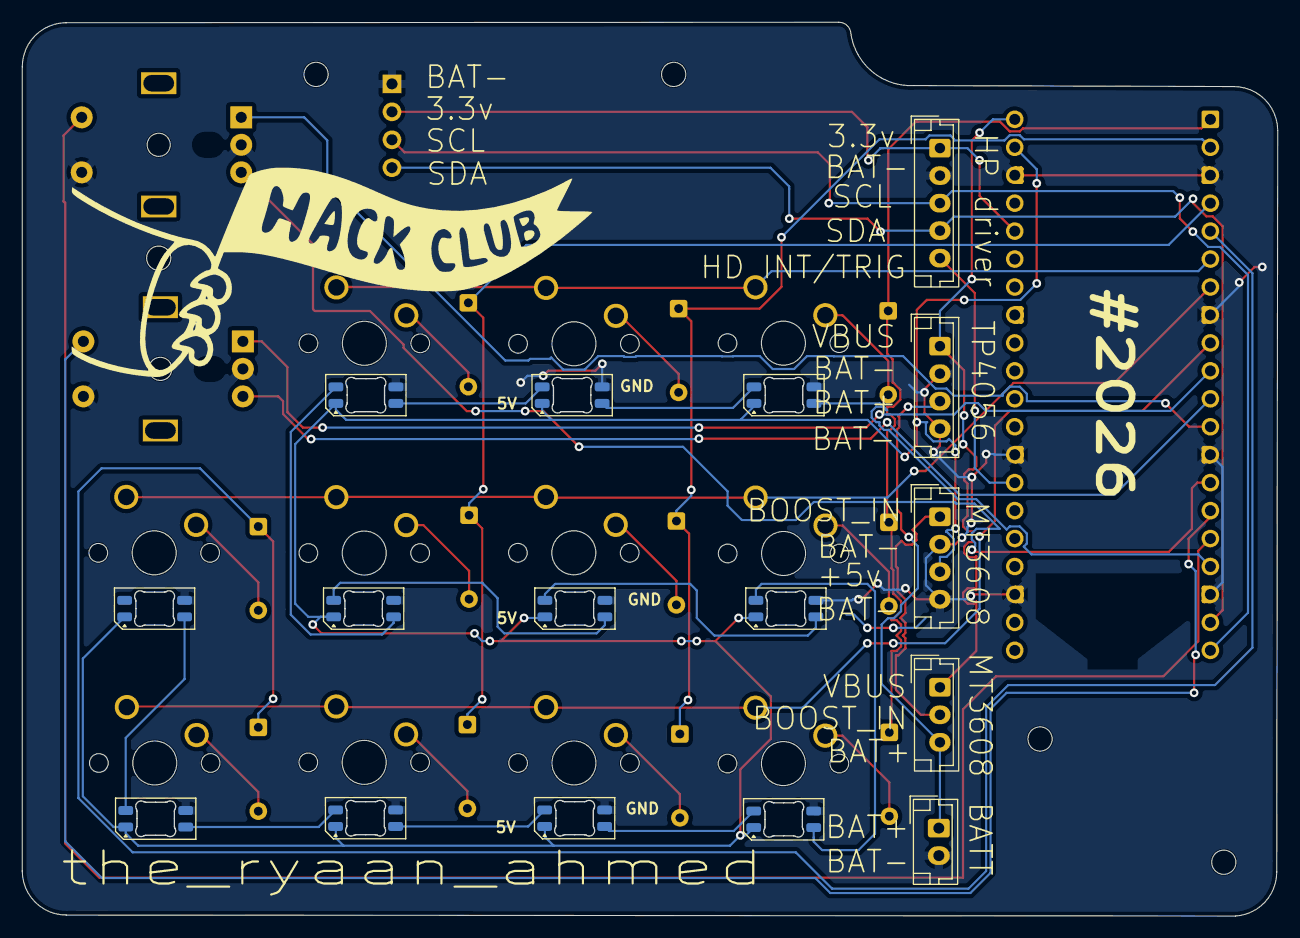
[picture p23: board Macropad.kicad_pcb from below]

Board: 2 copper layers, 114.1 x 81.2 mm, 42 parts (16 on the bottom side), 44 nets.

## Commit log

2026-07-25 Update JOURNAL.md with July 23rd assembly details
    Documented the process of soldering components onto the PCB, including challenges faced with SMD electronics and alignment issues with switches.
2026-09-30 Add build guide with step-by-step instructions
    Added detailed steps for building the device.
